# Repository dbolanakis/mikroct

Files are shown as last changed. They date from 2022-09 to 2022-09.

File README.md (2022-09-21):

# Rebuild An RC Car With ESP32 & Arduino Code
The present document provides all the information needed to rebuild an RC CAR from scratch using ESP32-based microcontroller units (MCUs), programmed in Arduino environment. The current project applies to the 1:16 Xinlehong (XLH)9136 model, but can be easily adapted to any RC Car model that incorporates:

a) DC motor for the forward/backward (FW/BW) movement of the car,

b) 3-wireServo Motor (operating at 5V) for the control of the steering wheel,

c) 2S LiPo battery (of 7.4 nominal voltage or perhaps of higher voltage if taking into consideration the specifications and limitations of the boards held by the proposed system).

To complile this project with Arduino IDE you need to install:
1) ESP32 package (run Boards Manager in Arduino IDE)
2) Servo ESP32 library, available at: https://github.com/RoboticsBrno/ServoESP32
3) Adafruit_INA219, available at: https://github.com/adafruit/Adafruit_INA219
4) ThingPulse OLED SSD1306, available at: https://github.com/ThingPulse/esp8266-oled-ssd1306

Follow a step-by-step guide through a playlist of 5 short videos found below:

https://www.youtube.com/channel/UC-wGLN7KYQ-hoKo3BcTTFVg

More code examples for Arduino can be found below:
https://mikroct.com/

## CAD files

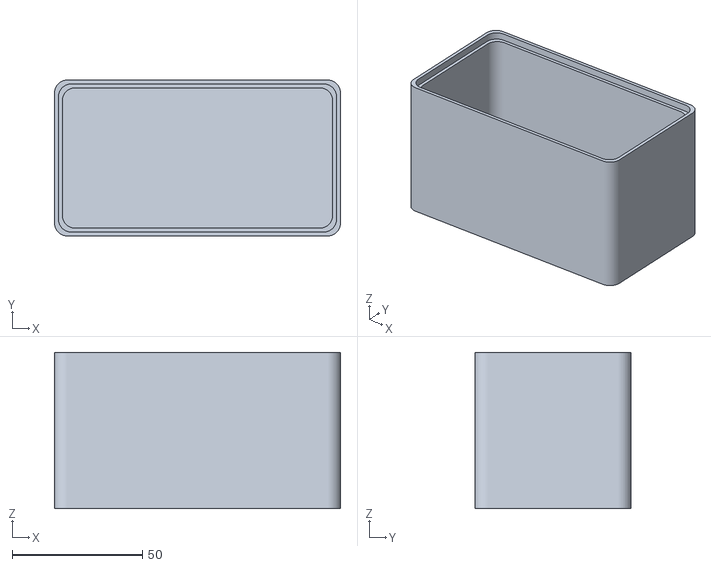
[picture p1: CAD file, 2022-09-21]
Enclosure.stl
110.0 x 60.0 x 60.0

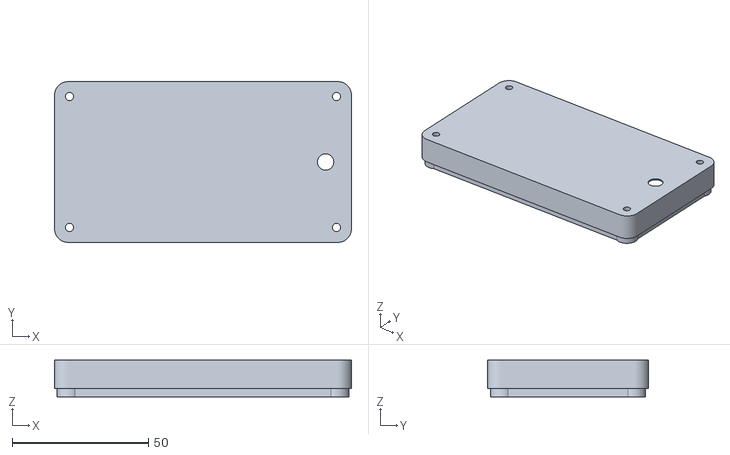
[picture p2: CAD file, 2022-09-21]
Lid.stl
109.0 x 59.0 x 13.5

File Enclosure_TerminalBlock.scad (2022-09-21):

$fn=50;
// Create an enclosure using 4 cylinders connected to each other with hull()

// Dimension of enclosure
CylinderRadius=5; //radious of enclosure corners
Width=110;  //x //first version 110
Length=60;  //y //first version 60
Height=60;  //z //first version 60
WallThickness=3;
lid_thickness=3;
lid_lip=WallThickness/2;

ScrewSockets_diameter=9;
hole_diameter=3; //screw's size if using lid


lid_tolerance=0.5;
lid_HEIGHT = 13.5;


module Chassis(x,y,z,h,r){
    translate([ x , y, z])   cylinder(r=r,h=h);
    translate([-x,  y, z])   cylinder(r=r,h=h);
    translate([-x, -y, z])   cylinder(r=r,h=h);
    translate([ x, -y, z])   cylinder(r=r,h=h);
}

// Width and Lenght should be divided by 2 because it draws the object over zero, while height is applied on possitive Z axes only
// CylinderRadious should be subtracted from Width and Length of the box, otherwise the outer dimensions will become larger
// Test the following line to see the Chassis of the box
//!hull()  Chassis(x=Width/2-CylinderRadius,y=Length/2-CylinderRadius,z=0,h=Height,r=CylinderRadius);



difference(){ // remove from Chassis the Hollow and the Lip
    hull(){ //create Chassis of enclosure
        Chassis(
            x=Width/2 -CylinderRadius,
            y=Length/2 - CylinderRadius,
            z=0,
            h=Height,
            r=CylinderRadius);
    }

    hull(){ //create inside Hollow of enclosure (i.e., the same as Chassis of enclosure decreased by WallThickness)
    //HOLLOWS STARTS FROM Z=WallThickness   
        Chassis(
            x=Width/2 - CylinderRadius - WallThickness,
            y=Length/2 - CylinderRadius - WallThickness,
            z=WallThickness, //thickness of bottom area
            h=Height,
            r=CylinderRadius);
    }
    //*
    hull(){ //lip inside the enclosure
    //LID STARTS FROM Z=Height of box minus lid_thickness    
        Chassis(
            x=Width/2 - CylinderRadius - lid_lip,
            y=Length/2 - CylinderRadius - lid_lip,
            z=Height - lid_thickness, //leave a gap from the upper arrea of the box, equal to lid_thickness
            h=Height, // just not to confuse OpenSCAD
            r=CylinderRadius);
    }  //*/
    
    //Terminal Block
    translate([ -Width/2 - WallThickness/2, 0, Height/2]) rotate([0,90,0]) cylinder(h=WallThickness*2, d=12);
}
//*


difference(){
    Chassis( //Screw Sockets (place them inside the Wall/thickness/2 because the box is aligned over zero of axis, and then subtract the raius of the Screw Sockets, i.e. diameter/2)
        x=Width/2 - WallThickness/2  - ScrewSockets_diameter/2,
        y=Length/2  - WallThickness/2  - ScrewSockets_diameter/2,
        z=WallThickness - 0.5, //place them 0.5mm inside the bottom wall
        h=Height - WallThickness - lid_thickness + 0.5,
        r=ScrewSockets_diameter/2);
    
    Chassis( //screw holes
        x=Width/2 - WallThickness/2 - ScrewSockets_diameter/2,
        y=Length/2 - WallThickness/2 - ScrewSockets_diameter/2,
        z=WallThickness , 
        h=Height - WallThickness - lid_thickness + 0.5 ,
        r=hole_diameter/2);
}

//LID STARTS HERE !!!! place ! mark before the difference to stl the LID only
#difference(){
union() {
    difference(){
      difference(){
        hull(){ //lid
            Chassis(
                x=Width/2 - CylinderRadius - WallThickness/2 - lid_tolerance,
                y=Length/2 - CylinderRadius - WallThickness/2 - lid_tolerance,
                z=Height - lid_thickness + 5, //+ 5, //move lid up
                h=lid_HEIGHT, //lid_thickness,
                r=CylinderRadius);   
        }
        hull(){ //lid hole
            Chassis(
                x=Width/2 - CylinderRadius - WallThickness/2 - lid_tolerance - lid_lip,
                y=Length/2 - CylinderRadius - WallThickness/2 - lid_tolerance - lid_lip,
                z=Height - lid_thickness + 5 , //+ 5, //move lid up
                h=13, //lid_thickness,
                r=CylinderRadius);   
        }
    }
    Chassis( //lid
        x=Width/2 - WallThickness/2 - ScrewSockets_diameter/2,
        y=Length/2 - WallThickness/2 - ScrewSockets_diameter/2,
        z=Height - lid_thickness +5, 
        h=Height - WallThickness - lid_thickness + lid_tolerance,
        r=hole_diameter/2 + lid_tolerance); 
    }    
    difference(){
      difference(){
        hull(){ //lid
            Chassis(
                x=Width/2 - CylinderRadius - WallThickness/2 - lid_tolerance,
                y=Length/2 - CylinderRadius - WallThickness/2 - lid_tolerance,
                z=Height - lid_thickness + 5, //+ 5, //move lid up
                h=lid_HEIGHT, //lid_thickness,
                r=CylinderRadius);   
        }
        hull(){ //lid hole
            Chassis(
                x=Width/2 - CylinderRadius - WallThickness/2 - lid_tolerance - lid_lip,
                y=Length/2 - CylinderRadius - WallThickness/2 - lid_tolerance - lid_lip,
                z=Height - lid_thickness + 5 , //+ 5, //move lid up
                h=13, //lid_thickness,
                r=CylinderRadius);   
        }
    }
    Chassis( //lid
        x=Width/2 - WallThickness/2 - ScrewSockets_diameter/2,
        y=Length/2 - WallThickness/2 - ScrewSockets_diameter/2,
        z=Height - lid_thickness +5, 
        h=Height - WallThickness - lid_thickness + lid_tolerance,
        r=hole_diameter/2 + lid_tolerance); 
    }

    difference(){
        Chassis( //Screw Sockets (place them inside the Wall/thickness/2 because the box is aligned over zero of axis, and then subtract the raius of the Screw Sockets, i.e. diameter/2)
            x=Width/2 - WallThickness/2  - ScrewSockets_diameter/2,
            y=Length/2  - WallThickness/2  - ScrewSockets_diameter/2,
            z=Height - lid_thickness + 5, //+ 5, //move up to the lid 
                //z=WallThickness - 0.5, //place them 0.5mm inside the bottom wall
            h=lid_HEIGHT /*Height - WallThickness - lid_thickness + 0.5*/,
            r=ScrewSockets_diameter/2);
        
        Chassis( //screw holes
            x=Width/2 - WallThickness/2 - ScrewSockets_diameter/2,
            y=Length/2 - WallThickness/2 - ScrewSockets_diameter/2,
             z=Height - lid_thickness, //+ 5, //move up to the lid
                //z=WallThickness , 
            h=Height - WallThickness - lid_thickness + 0.5 ,
            r=hole_diameter/2);
    }
    
////////////////// create equal distance with the outer of the box
    difference(){
      difference(){
        hull(){ //lid
            Chassis(
                x=Width/2 - CylinderRadius  - lid_tolerance,
                y=Length/2 - CylinderRadius  - lid_tolerance,
                z=Height - lid_thickness + 5 + lid_thickness, //+ 5, //move lid up
                h=lid_HEIGHT - lid_thickness,
                r=CylinderRadius);   
        }
        hull(){ //lid hole
            Chassis(
                x=Width/2 - CylinderRadius - WallThickness/2 - lid_tolerance - lid_lip,
                y=Length/2 - CylinderRadius - WallThickness/2 - lid_tolerance - lid_lip,
                z=Height - lid_thickness + 5 , //+ 5, //move lid up
                h=lid_HEIGHT-0.5, //lid_thickness,
                r=CylinderRadius);   
        }
    }
    Chassis( //lid
        x=Width/2 - WallThickness/2 - ScrewSockets_diameter/2,
        y=Length/2 - WallThickness/2 - ScrewSockets_diameter/2,
        z=Height - lid_thickness +5, 
        h=Height - WallThickness - lid_thickness + lid_tolerance,
        r=hole_diameter/2 + lid_tolerance); 
    }     
}

//// Switch hole for LID
    //Terminal Block
    translate([ Width/2 - 10, 0, Height-lid_thickness+5]) rotate([0,0,90]) cylinder(h=lid_HEIGHT, d=6);
}

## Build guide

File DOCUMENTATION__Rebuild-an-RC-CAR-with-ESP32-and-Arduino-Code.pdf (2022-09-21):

1

1

IN THIS DOCUMENT

1.1 | Overview of the 1:16 RC car.
1.2 | Rebuilding electronics of the RC car.
1.3 | Rebuilding electronics of the Remote Control.
1.4 | Bill of Materials.

## Rebuild an RC CAR with ESP32 & Arduino Code

he present document provides all the information needed to rebuild an RC CAR
from | scratch | using | ESP32-based
microcontroller units (MCUs), programmed in Arduino environment. The current project applies to the 1:16 Xinlehong (XLH) 9136 model, but can be easily adapted to any RC Car model that incorporates:
a) DC motor for the forward/backward (FW/BW) movement of the car,
b) 3-wire Servo Motor (operating at 5V) for the control of the steering wheel,
c) 2S LiPo battery (of 7.4 nominal voltage or perhaps of higher voltage if taking into consideration the specifications and limitations of the boards held by the proposed system).

T

2 | Rebuild an RC CAR with ESP32 & Arduino Code

### Overview of the 1:16 RC car

Figure 1–1 presents the chassis of the RC Car used by the current project. The car incorporates:
a) 2S battery,
b) electronic speed controller (ESC) with an encompassed RF receiver, which receives commands from the Remote-Control device and drives the DC motor of the car (i.e., FW/BW movement) as well as the Servo motor (i.e., the control of the steering wheel),
c) 390 DC motor (of JST XH type of female connector),
d) 5-wire Servo motor.
The 5-wire servo (depicted in Figure 1–2) is currently replaced with a compatible 3-wire servo, which is a more common choice for that kind of RC cars. Despite the servo replacement, the battery’s connector has been swapped to the more common XT-60 type of female connector.

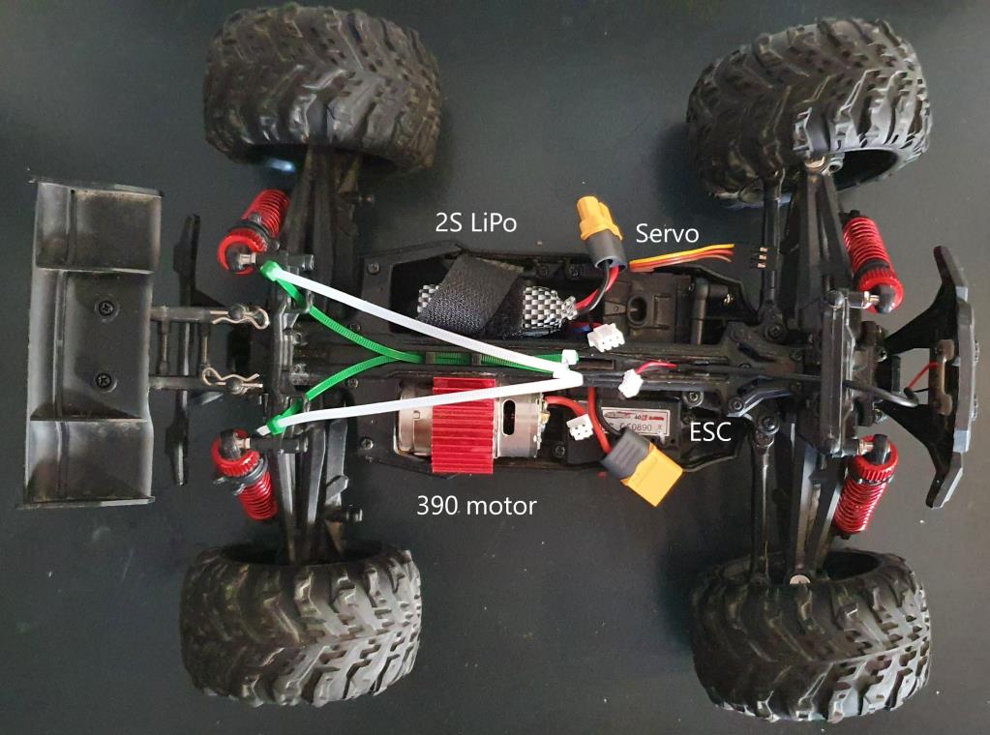
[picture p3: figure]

Figure 1–1 Chassis of the 1:16 RC Car.

Overview of the 1:16 RC car | 3

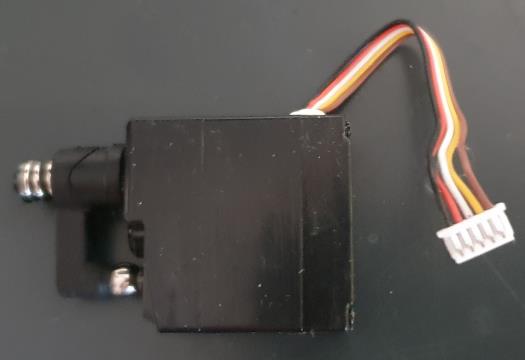
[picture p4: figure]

Figure 1—2 The originally 5-wire Servo incorporated by the 9136 RC Car.

Figure 1–3 illustrates the connections of the DC motor as well as the 5-wire Servo on the original ESC of the RC car system. It should be noted that the original ESC employs also a 2-pin JST PH type of female connector which is used for driving the RC car’s lights; a function that will be not used in the recreated version of the system presented herein.

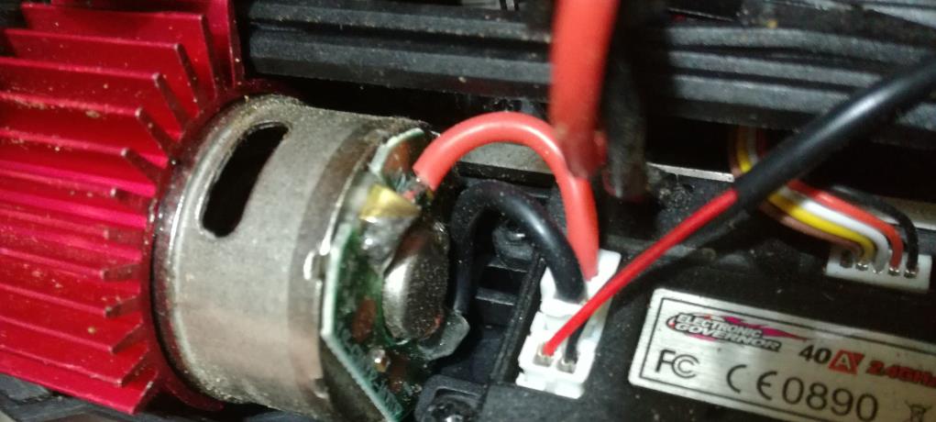
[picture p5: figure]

Figure 1—3 DC motor and 5-wire Servo connected to the ESC originally found on the RC Car.

Figure 1–4 depicts the original inner electronics of the Remote Control, which sends commands to the RC car. The device obtains power from 3 x AA batteries and encompasses two fundamental (5K) potentiometers which are used to control the FW/BW movement of the car as well as the steering wheel. Two more potentiometers on the top of the printed-circuit board (PCB) of the device are used to a) diminish the maximum speed of the car, and b) adjust the servo’s quiescent point so as the front wheels of the car are aligned to move in straight line.
In Figure 1–4 we have removed all but the two fundamental potentiometers that drive the car FW/BW and turn it left/right (L/R). Each one of these two potentiometers

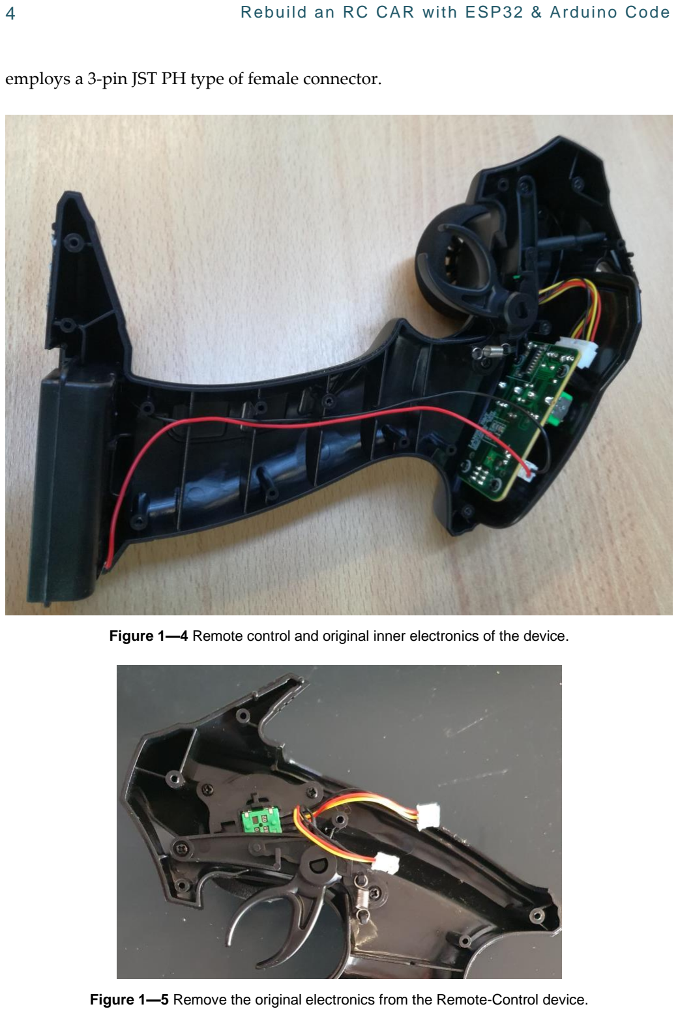
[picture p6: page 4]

employs a 3-pin JST PH type of female connector.

Figure 1—4 Remote control and original inner electronics of the device.

Figure 1—5 Remove the original electronics from the Remote-Control device.

Rebuilding electronics of the RC car | 5

### Rebuilding electronics of the RC car

Figure 1–6 presents the re-designed electronics of the RC Car. An on/off switch is used to power on/off the RC car, which three connectors are used for connecting the DC motor, battery and servo to the boards of the system.

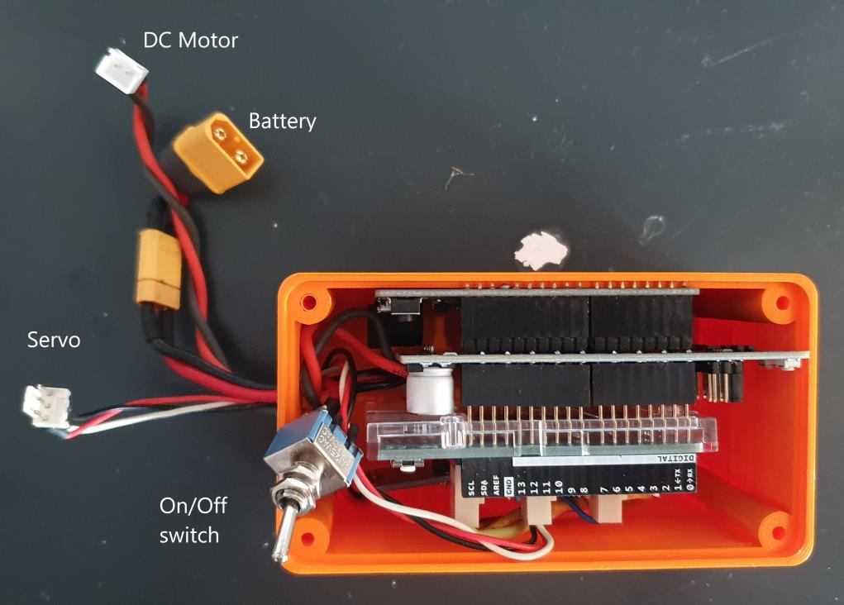
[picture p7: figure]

Figure 1—6 3D printed enclosure and user-defined electronics of the RC Car.

The separated electronics of the RC Car system are illustrated in Figure 1–7. The brain of the system constitutes an ESP32-based microcontroller (that is, WeMos D1 R32 board) which is also able to provide an RF interface with an equivalent microcontroller at the Remote-Control device. A DC Motor driver board system (that is, the SHIELD-MDD10 by Cytron Technologies) obtains power from the 2S LiPo battery and (through an H-bridge motor driver) controls the speed and direction (FW/BW) of the DC Motor. The third board of the RC Car system, that is, the Motion shield, employs BNO055 orientation sensor. While this board is used for future upgrades of the system (e.g., applying a drift functionality to the RC Car), it employs connectors which are used for the interconnection of various electronics of the system to the microcontroller board. One additional breakout board (that is, the INA219 current measuring module) provides information on the current consumed by the RC Car electronics.

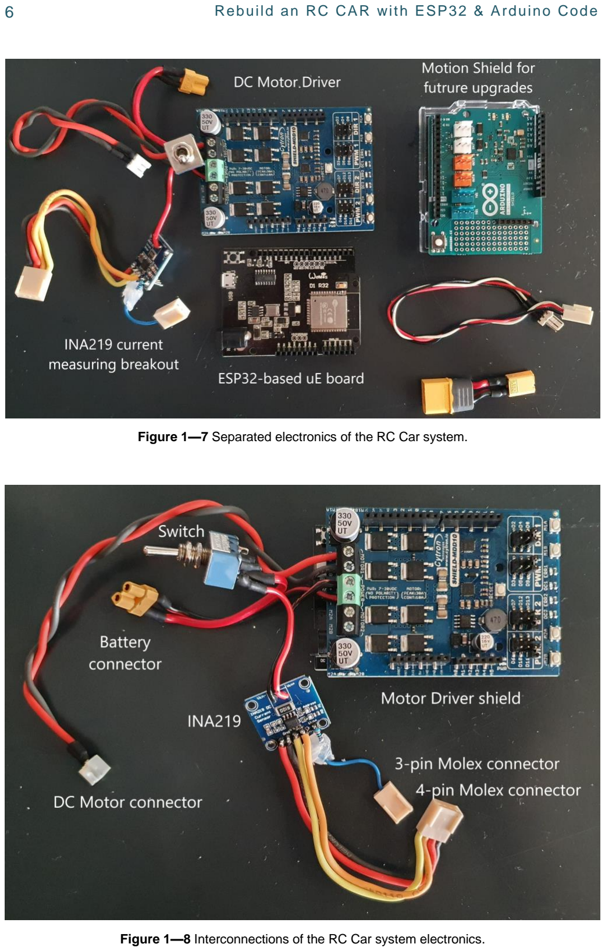
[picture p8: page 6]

Figure 1—7 Separated electronics of the RC Car system.

Figure 1—8 Interconnections of the RC Car system electronics.

Rebuilding electronics of the RC car | 7

Figure 1–8 presents the interconnections of the RC Car system electronics. In detail, the positive pole of the battery is connected to one of the two edges of the on/off switch. The other edge of the switch is connected to the positive input pin of INA219 module. The other (i.e., negative) input pin of INA219 is connected to the positive input of the power clamp of the Motor Driver shield (i.e., the green one), while the negative input of the same clamp is returned back to the negative pole of the battery.
Moreover, the I2C control of the INA219 module is achieved through 4-pin (2.54mm) Molex connector, which is directed to the corresponding pins of the microcontroller board (via the Motion shield connectors). Finally, the battery’s two poles are connected (via the INA219 module) to a voltage divider of 2 x 10K resistors, and the divided-by-two (7.4V) nominal voltage of the battery is directed to an Analog Pin of the microcontroller (i.e., the blue wire) through the 3-pin Molex connector.

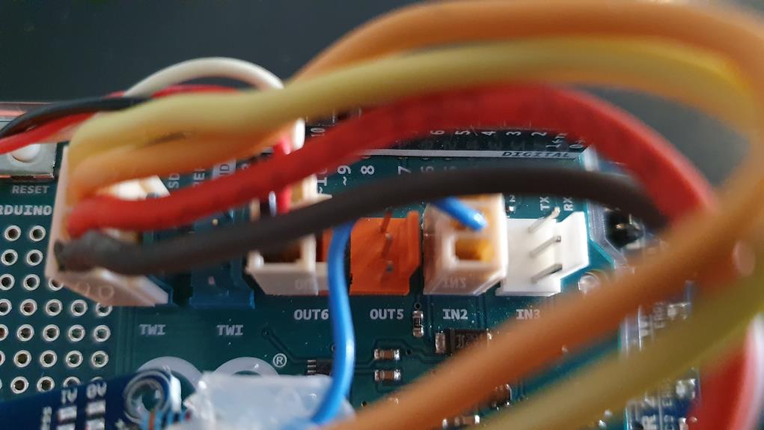
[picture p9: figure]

Figure 1—9 Connections through the Motion shield.

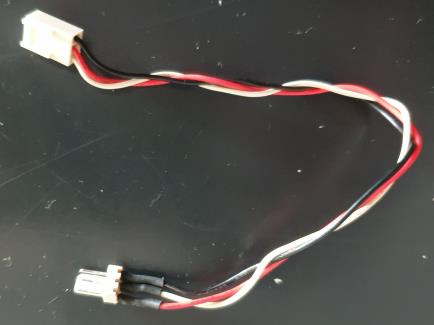
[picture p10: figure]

Figure 1—10 Connections through the Motion shield.

Figure 1–9 presents aforementioned connections of INA219 module to the ESP32 microcontroller board, through the connectors found on the Motion shield (connectors referred to as TWI and IN2). The additional OUT6 connector holds the cable for driving the Servo motor (through a PWM pin). This cable is depicted in Figure 1–10.

Rebuilding electronics of the Remote Control | 9

### Rebuilding electronics of the Remote Control

The separated electronics of the Remote-Control system are illustrated in Figure 1–

### 11. The brain of the system constitutes an ESP32-based microcontroller (that is, the C3

mini V1.0.0) which is also able to provide an RF interface to the equivalent microcontroller of the RC Car system.

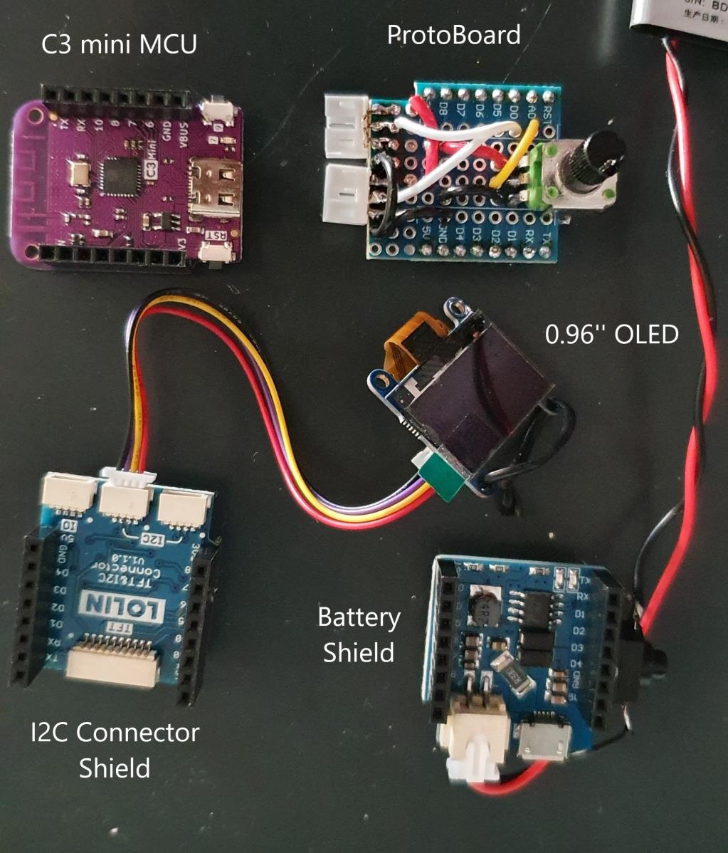
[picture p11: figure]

Figure 1—11 Separated electronics of the Remote Control.

A Battery Shield along with a 3.7V battery and an on/off switch provides power to the Remote-Control system. Information acquired by the RC Car (i.e., the percentage of the remaining battery, the battery’s voltage and current consumed by the RC Car system) are depicted by an 0.96’’ OLED, which is connected to the I2C pins of the MCU board through the corresponding I2C Connector Shield. Those reading are primarily needed because the LiPo battery should not drop below 6.2V so as to avoid a permanent damage. Finally, a ProtoBoard shield is used to accept the two potentiometers of the Remote Control that control FW/BW and L/R movements (see Figure 1–5), as well as to employ an additional 5K potentiometer for the alignment of the steering wheel (through the adjustment of the Servo’s quiescent point).
The connections of the protoboard are quite simple. In detail, the inner pin of each potentiometer is driven to an Analog Pin of the MCU, while the other two potentiometer pins are connected to the power and ground pins respectively.

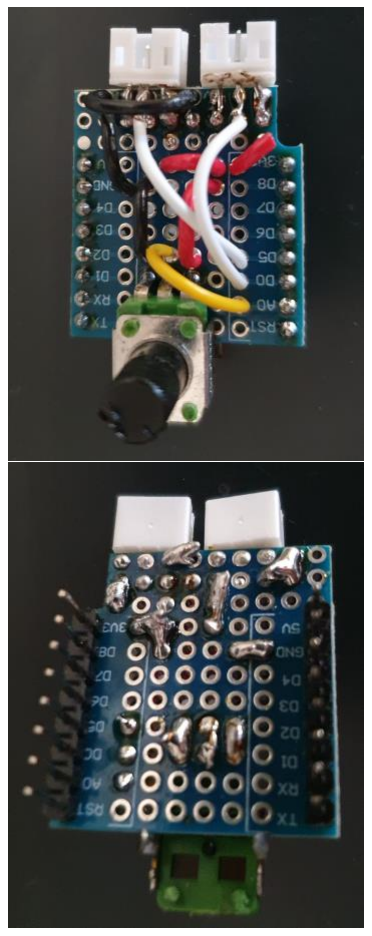
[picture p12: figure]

Figure 1—12 ProtoBoard Shield of the Remote Control.

Bills of Materials | 11

### Bills of Materials

Remote Control:
1. (2x) JST PH Connector Male 3-Pin 2.0mm ➔ Steer and Wheels control
2. (1x) Potentiometer Linear 5Kohm/6mm , Vertical ➔ Servo adjustment
3. (1x) ProtoBoard Shield ➔ to connect the three aforementioned potentiometers
a. (2x) Pin Header 1x8 Male 2.54 mm
4. (1x) C3 Mini V1.0.0 Microcontroller Compatible with LOLIN D1 mini shields
a. (2x) long 10.5mm / 8pin female header ➔ Stackable headers for the μΕ
5. (1x) LOLIN lithium (LiPo) Battery shield ➔ Provide power to the remote control
a. (2x) Long 10.5mm / 8pin female header ➔ Stackable headers for the Bat. Shield
6. (1x) 3.7 V 1S LiPo battery ➔ Battery for the remote control
7. (1x) Push Button - Latching Black (12x8x8.2mm) ➔ On/Off switch
8. (1x) TFT I2C Connector Shield ➔ to attach I2C OLED 0.96 Shield
a. (2x) Long 10.5mm / 8pin female header ➔ Stackable headers for the I2C Connector Shield
9. (1x) I2C OLED 0.96 Shield V1.0.0 (128x64 pixels) ➔ Display
a. I2C Cable 100mm 10cm for LOLIN (WEMOS) SH1.0 4P double head cable

RC Car:
1. (1x) XT60 Male connector ➔ Battery connection
a. (1x) XT30 Male/Female connector ➔ attach/detach the Battery connector
2. (1x) 3-pin Mole Male connector (2.54mm) ➔ Servo connection
3. (1x) 2-pin JST XH Male connector ➔ DC Motor connection
4. (1x) On/Off switch
5. (1x) INA219 breakout board
a. (2x) 10K resistors ➔ voltage divider for the LiPo battery
b. (1x) 3-pin Molex Female connector
c. (1x) 4-pin Molex Female connector
6. (1x) Motor Driver shield
7. (1x) WeMos D1 R32 ESP32-based Microcontroller board
8. (1x) SHIELD-MDD10 Motor Driver by Cytron Technologies
9. (1x) 3-pin Molex Male/Female connector ➔ Servo connection cable
10. (1x) Motion Shield (future upgrades)

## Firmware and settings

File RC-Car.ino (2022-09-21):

#include <Wire.h>
#include <Adafruit_INA219.h>
#include <esp_now.h>
#include <WiFi.h>
#include <Servo.h>
Servo myservo;
Adafruit_INA219 ina219;

uint8_t broadcastAddress[] = {0x60, 0x55, 0xF9, 0x21, 0xCC, 0xD4}; //C3 MINI MAC Address on Remote Control

int LiPo=A7, Voltage, Voltage_Mapped; // Read the (divided by 2) Battery voltage from Analog Pin 7
unsigned char Battery;
float current_mA;
unsigned int I_mA;
int Receive_Timeout;
// Steering Wheel initally alignment 
const int SERVO_QUIESCENT = 90; 
// 4WD Movement
const int pwmMOTOR = 13;  // Forward/Backward PWM pin
const int dirMOTOR = 12;  // Forward/Backward DIR pin
const int pwmChannel_MOTOR = 2; //!!//SERVO is attached to pwm channel 2
// PWM settings  
const int pwmFreq = 50;  
const int pwmResolution = 8; // 8bits (0-255)
// Servo is initially set at 90 degrees
unsigned char servoValue=SERVO_QUIESCENT;

// Variables to store incoming readings
int FW_BW, L_R, L_R_Adj;

// Variables to drive the RC Car
int CAR_FW, CAR_BW, CAR_LEFT, CAR_RIGHT;



// Structure holding values to be sent by the REMOTE CONTROL
typedef struct RemoteControl_Outgoing {
    signed char ForwardBackward;
    signed char LeftRight;
    signed char LeftRight_Adj;
} RemoteControl_Outgoing;
RemoteControl_Outgoing CAR;

// Create a struct_message to hold incoming readings sent by the REMOTE CONTROL
RemoteControl_Outgoing incomingReadings;

// Structure holding values to be sent by the RC CAR
typedef struct CAR_Outgoing {
    unsigned char BatVoltage;
    unsigned int  Current;
} CAR_Outgoing;
CAR_Outgoing REMOTE_CONTROL;


esp_now_peer_info_t peerInfo;


// Callback when data is received
void OnDataRecv(const uint8_t * mac, const uint8_t *incomingData, int len) {

  Receive_Timeout=0;
  
  memcpy(&incomingReadings, incomingData, sizeof(incomingReadings));
  FW_BW = incomingReadings.ForwardBackward;
  L_R = incomingReadings.LeftRight;
  L_R_Adj = incomingReadings.LeftRight_Adj;
  //!!//Serial.println ( (String) "FW_BW=" + FW_BW + '\t' + '\t' + "L_R=" + L_R + '\t' + '\t' + "L_R_Adj=" + L_R_Adj ); 
  
 // Prepare PWM configuration for the RC Car (Forward: 1 to 33 , Backward: -1 to -23  , Left: 1 to 25 , Right: -1 to -31)
  if (FW_BW>0)    CAR_FW = map(FW_BW,1,33,1,255); 
  if (FW_BW<0)    CAR_BW = map(FW_BW,-1,-23,1,255);
  if (FW_BW==0)   CAR_BW = CAR_FW = 0;
  if (L_R>0)      CAR_LEFT = map(L_R,1,25,1,35);    //1,255); // Don't let servo to turn from 0-180 (instead from 1-255 map to 1-35);
  if (L_R<0)      CAR_RIGHT = map(L_R,-1,-31,1,35); //1,255); // thus the SERVO will turn from 90-35 to 90+35
  if (L_R==0)     CAR_RIGHT = CAR_LEFT = 0;
  Serial.println ( (String) '\t' + "CAR_FW=" + CAR_FW + '\t' + "CAR_BW=" + CAR_BW + '\t' + "CAR_LEFT=" + CAR_LEFT + '\t' + "CAR_RIGHT=" + CAR_RIGHT );
 // 4WD Movement: generate PWM signal
  if (CAR_FW>0 && CAR_BW==0) {
    digitalWrite(dirMOTOR,LOW);         //Forward
    ledcWrite(pwmChannel_MOTOR, (CAR_FW+CAR_BW) );
  }
  else if (CAR_BW>0 && CAR_FW==0) {
    digitalWrite(dirMOTOR,HIGH);        //Backward
    ledcWrite(pwmChannel_MOTOR, (CAR_FW+CAR_BW) );
  }
  else ledcWrite(pwmChannel_MOTOR, 0 );
 // Steering Wheel: Prepare & Write Servo value
  if (CAR_LEFT>0 && CAR_RIGHT==0) {
    servoValue = (unsigned char) (SERVO_QUIESCENT-CAR_LEFT+L_R_Adj) ;
  }
  else if (CAR_RIGHT>0 && CAR_LEFT==0) {
    servoValue = (unsigned char) (SERVO_QUIESCENT+CAR_RIGHT+L_R_Adj);
  }
  else servoValue = (unsigned char)(SERVO_QUIESCENT+L_R_Adj);
  myservo.write(servoValue); // Write Servo value
  //!!//Serial.println (servoValue);
  
  // Prepare Voltage and Current Measurements
  Voltage = analogRead(LiPo);
  Voltage_Mapped = map(Voltage,1,4095,1,63);
  Battery = (unsigned char)Voltage_Mapped; 
  //read Current
  float current_mA = ina219.getCurrent_mA();
  I_mA = (unsigned int)current_mA; 
  // Transmit Voltage and Current data to the Remote Control device
  REMOTE_CONTROL.BatVoltage = Battery;
  REMOTE_CONTROL.Current = I_mA;
  esp_err_t result = esp_now_send(broadcastAddress, (uint8_t *) &REMOTE_CONTROL, sizeof(REMOTE_CONTROL));
  
}

  // Callback when data is sent
  void OnDataSent(const uint8_t *mac_addr, esp_now_send_status_t status) {
  }

  

 
void setup() {
  
  ina219.begin();
  
  // 4WD Movement
  pinMode(dirMOTOR, OUTPUT);                             // Forward/Backward DIR pin
  ledcSetup(pwmChannel_MOTOR, pwmFreq, pwmResolution);   // configure PWM 
  ledcAttachPin(pwmMOTOR, pwmChannel_MOTOR);             // attach PWM channel to the GPIO pin to be controlled
  // Steering Wheel
  myservo.attach(27);     // attach Servo pin
  
  Serial.begin(115200);
  WiFi.mode(WIFI_STA);
  WiFi.disconnect();
  esp_now_init();
  WiFi.setTxPower(WIFI_POWER_8_5dBm);
  memcpy(peerInfo.peer_addr, broadcastAddress, 6);  // Register peer
  peerInfo.channel = 0;  
  peerInfo.encrypt = false;
  esp_now_add_peer(&peerInfo);                     // Add peer        
      
  // Register for a callback function that will be called when data is received
  esp_now_register_recv_cb(OnDataRecv);

}
 
void loop() {
  Receive_Timeout++;
  if (Receive_Timeout > 200000) {
    ledcWrite(pwmChannel_MOTOR, 0 );
    Receive_Timeout=200000; // stall counter (@ value higher than 200000) until RF communication is restored (about 2sec delay)
  }
}
  

  

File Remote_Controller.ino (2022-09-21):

#include <esp_now.h>
#include <WiFi.h>
#include <Wire.h>
#include "SSD1306Wire.h"
SSD1306Wire display(0x3d, SDA, SCL);   // I2C Addr = 0x3D
typedef void (*Demo)(void);
int demoMode = 0;

uint8_t broadcastAddress[] = {0x78, 0xE3, 0x6D, 0x1B, 0x1B, 0xC8}; //D1R32 MAC Address on RC Car

float Battery;
int Battery_Percentage;
unsigned int I_mA;
int Wheels=A2, Steering=A1, ServoAdj=A0;  // Define Analog Channels
int ADC_Resolution = 4095;                //ADC InputRange: 0-3V3; thus lsb=InputRange/2^12=0.8mV                
int ADC_Wheels, ADC_Steering, ADC_ServoAdj, Wheels_Mapped, Steering_Mapped, ServoAdj_Mapped; 
int FW_BW, L_R; 
const int SteeringQ=35, WheelsQ=27; // quiescent point steering & wheels
const int Hysteresis = 3;           // add hysteresis from quiescent point


// Structure holding values to be sent by the REMOTE CONTROL
typedef struct RemoteControl_Outgoing {
    signed char ForwardBackward;
    signed char LeftRight;
    signed char LeftRight_Adj;
} RemoteControl_Outgoing;
RemoteControl_Outgoing CAR;

// Structure holding values to be sent by the RC CAR
typedef struct CAR_Outgoing {
    unsigned char BatVoltage;
    unsigned int  Current;
} CAR_Outgoing;
CAR_Outgoing REMOTE_CONTROL;

// Create a struct_message to hold incoming readings sent by the RC CAR
CAR_Outgoing incomingReadings;


esp_now_peer_info_t peerInfo;


// Callback when data is received
void OnDataRecv(const uint8_t * mac, const uint8_t *incomingData, int len) {
  memcpy(&incomingReadings, incomingData, sizeof(incomingReadings));
  Battery = (float) incomingReadings.BatVoltage;
  Battery = (Battery * 3.3/63.0) * 4.0; // ADC for battery is mapped in the RC Car system from 1-4095 to 1-31(0.1V resolution)
  Battery_Percentage = (int)(Battery*100.0);
  Battery_Percentage = map(Battery_Percentage,640,840,0,100);
  //Serial.println(incomingReadings.Current);
  //!!//Serial.println((String) "Battery=" + Battery + '\t' + "Battery_Percentage=" + Battery_Percentage + '%' + '\t' + "Current=" + incomingReadings.Current); 
}

// Callback when data is sent
void OnDataSent(const uint8_t *mac_addr, esp_now_send_status_t status) {
}



void setup() { 
  display.init();
  display.flipScreenVertically();
  display.setFont(ArialMT_Plain_10); 
  //!!//Serial.begin(115200);
  WiFi.mode(WIFI_STA);
  WiFi.disconnect();
  esp_now_init();
  WiFi.setTxPower(WIFI_POWER_8_5dBm);
  esp_now_register_send_cb(OnDataSent);              // Get the status of Trasnmitted packet
  memcpy(peerInfo.peer_addr, broadcastAddress, 6);   // Register peer
  peerInfo.channel = 0;  
  peerInfo.encrypt = false;
  esp_now_add_peer(&peerInfo);                      // Add peer
  esp_now_register_recv_cb(OnDataRecv);    // Register for a callback function that will be called when data is received
}

void drawProgressBarDemo() { 
  // draw the progress bar
  display.drawProgressBar(0, 0/*32*/, 120, 10, Battery_Percentage);
  // draw the percentage as String
  display.setTextAlignment(TEXT_ALIGN_CENTER);
  display.drawString(64, 15, "BATTERY= " + String(Battery_Percentage) + "%");
}
Demo demos[] = {drawProgressBarDemo}; ///Demo demos[] = {drawFontFaceDemo, drawTextFlowDemo, drawTextAlignmentDemo, drawRectDemo, drawCircleDemo, drawProgressBarDemo, drawImageDemo};
int demoLength = (sizeof(demos) / sizeof(Demo));


void loop() {
  if (incomingReadings.Current == 0) Battery=0;
  
  // based on a revision of ..Arduino\libraries\esp8266-oled-ssd1306-master\examples\SSD1306SimpleDemo
  display.clear();
  // draw the current demo method
  demos[demoMode]();
  display.setFont(ArialMT_Plain_16);
  display.setTextAlignment(TEXT_ALIGN_RIGHT);
  display.drawString(128, 48, String(Battery) + "V"); // Battery Voltage
  display.setTextAlignment(TEXT_ALIGN_LEFT);
  display.drawString(1, 48, String(incomingReadings.Current) + "mA" );///display.drawString(128, 54, String(millis()));
  // write the buffer to the display
  display.display();
    
  //Steering Wheel 
  ADC_Steering = analogRead(Steering);
  Steering_Mapped = map(ADC_Steering,160,4095,1,63); //Decrease Resolution of Steering Wheels
  //Serial.println((String) "Steering_Mapped=" + Steering_Mapped); 
  if (Steering_Mapped > SteeringQ+Hysteresis) L_R = Steering_Mapped - (SteeringQ+Hysteresis);     // LEFT (positive value)
  else if (Steering_Mapped < SteeringQ-Hysteresis) L_R = (Steering_Mapped-SteeringQ+Hysteresis);  //RIGHT (negative value)
  else L_R=0;

  //4WD Movement
  ADC_Wheels = analogRead(Wheels);  
  Wheels_Mapped = map(ADC_Wheels,1270,4095,1,63); //Decrease Resolution of Wheels
  if (Wheels_Mapped > WheelsQ+Hysteresis) FW_BW = Wheels_Mapped - (WheelsQ+Hysteresis);    //FORWARD  (positive value)
  else if (Wheels_Mapped < WheelsQ-Hysteresis) FW_BW = (Wheels_Mapped-WheelsQ+Hysteresis); //BACKWARD (negative value)
  else FW_BW=0;

  //Servo adjustment (Steering Wheel alignment) 
  ADC_ServoAdj = analogRead(ServoAdj); 
  ServoAdj_Mapped = map(ADC_ServoAdj,0,4095,0,32); //Decrease Resolution of Servo trimming value
  ServoAdj_Mapped -= 16;


  //Serial.println((String) "Forward/Backward=" + FW_BW + '\t' + "Left/Right=" + L_R + '\t' + "Steering Alignment=" + ServoAdj_Mapped); 

  // Prepare & Transmit data to the RC Car
  CAR.ForwardBackward = (signed char)FW_BW;
  CAR.LeftRight = (signed char)L_R;
  CAR.LeftRight_Adj =  (signed char)(ServoAdj_Mapped);
  esp_err_t result = esp_now_send(broadcastAddress, (uint8_t *) &CAR, sizeof(CAR));
}
